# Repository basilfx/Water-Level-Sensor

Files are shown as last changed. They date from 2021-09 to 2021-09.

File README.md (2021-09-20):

# Water Level Sensor
Capacitive water level sensor based on a custom Arduino-based board.

## Introduction
This project started as an experiment to see if a water level sensor (with
fixed intervals) could be built, using the Arduino
[ADCTouch](https://github.com/martin2250/ADCTouch) library and capacitive
sensors. Capacitive sensors have the advantage that they can be isolated from
water, creating a water-tight sensor.

In this repository, you can find the CAD designs, firmware and 3D printed
parts to create a water level sensor.

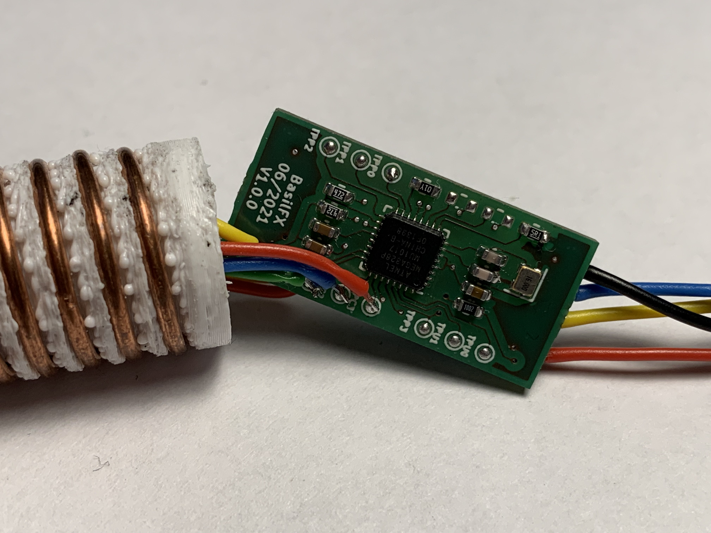
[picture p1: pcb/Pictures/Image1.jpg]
Image 1 of complete board.
[](pcb/Pictures/Image1.jpg)

## Features
* Small board that finds in a 19mm tube.
* 4 channels/board, can be daisy-chained up to 8 boards.
* I2C connection.
* Temperature sensor.

## Contents
* The `3d/` folder contains a 3D-printable designs for the necessary parts.
* The `applications/` folder contain applications and drivers that can interact
  with the sensor.
* The `firmware/` folder contains the Platform.IO-based firmware that runs on
  the sensors.
* The `pcb/` folder contains the Kicad schema and board design.

## My setup
Several proof of concepts have been built, to validate the idea and the
sensitivity of the setup in a 19mm PVC pipe (electrical conduit pipe). This
pipe was perfect for my 400 liter rain barrel, only occupying 0.5 L of water.

To create the fixed intervals, I 3D printed coils that I wound using 1.5 mm²
electrical wire. I could not get copper/aluminium tube that fitted exactly in
the 19mm tube, and this 'solution' somewhat expands against the inside of the
tube, ensuring as little as possible air between the tube and the coil.

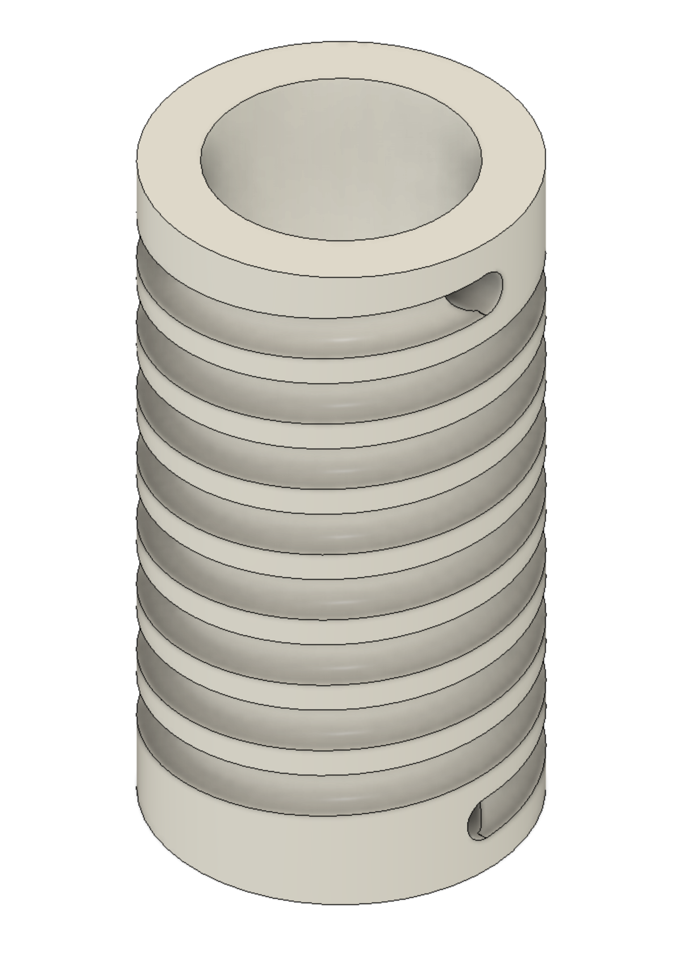
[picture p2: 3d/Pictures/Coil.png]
Actual assembly of the coil.
[](3d/Pictures/Coil.png)

In total, I used 4 sensor boards, connecting a total of 16 intervals, or
25 liter per interval. The picture below shows render of how one sensor board
is used for four intervals. Four of these assemblies are daisy-chained
together. The parent board is then connected to an external application to
read the sensor.

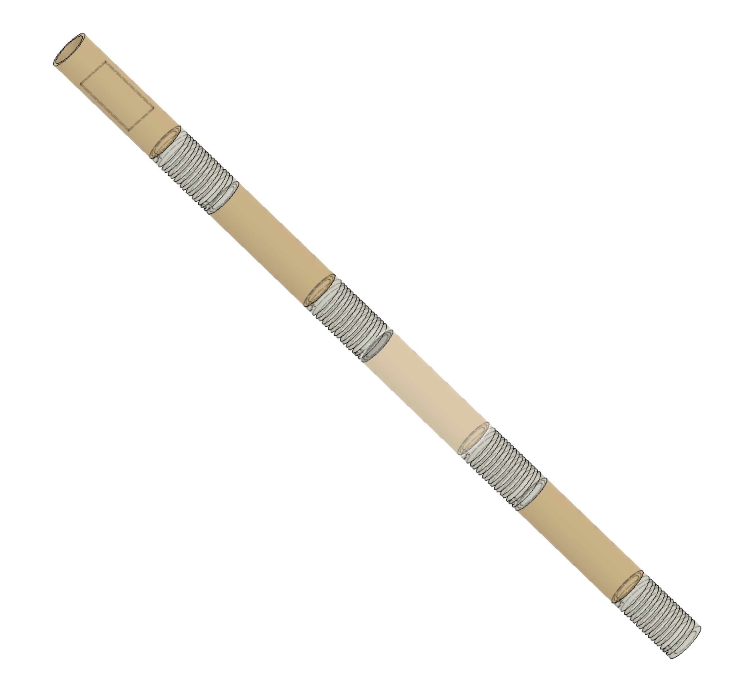
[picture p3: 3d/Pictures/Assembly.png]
3D render of assembly.
[](3d/Pictures/Assembly.png)

## License
The work in this repository is covered by CC BY-NC-SA 4.0. See the `LICENSE.md`
file for more information.

Some parts of this project are covered by a different license.

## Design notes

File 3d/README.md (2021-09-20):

# Water Level Sensor

## Pictures
[3D render of the coil.](Pictures/Coil.png)
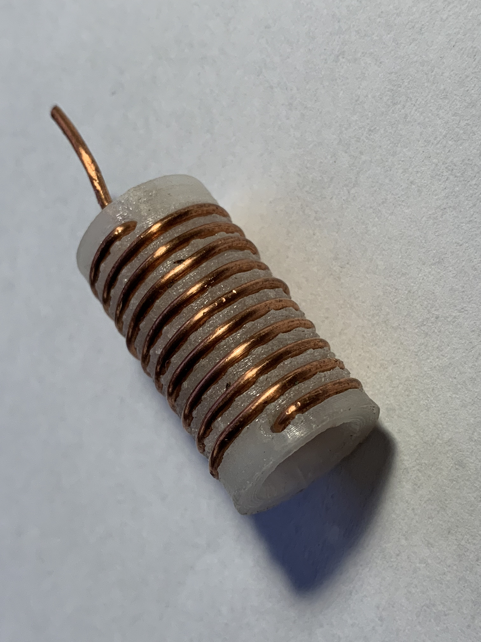
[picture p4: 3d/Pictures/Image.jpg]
Actual assembly of the coil.
[](Pictures/Image.png)

## Dimensions
The coil measures 19 mm x 30 mm.

## Print Settings
Print both parts in PETG at 0.2 mm layer height with 100% infill. Due to the
threads, it might not be as smooth as rendered, but that can be cleaned easily.

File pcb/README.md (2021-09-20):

# Water Level Sensor

## Pictures
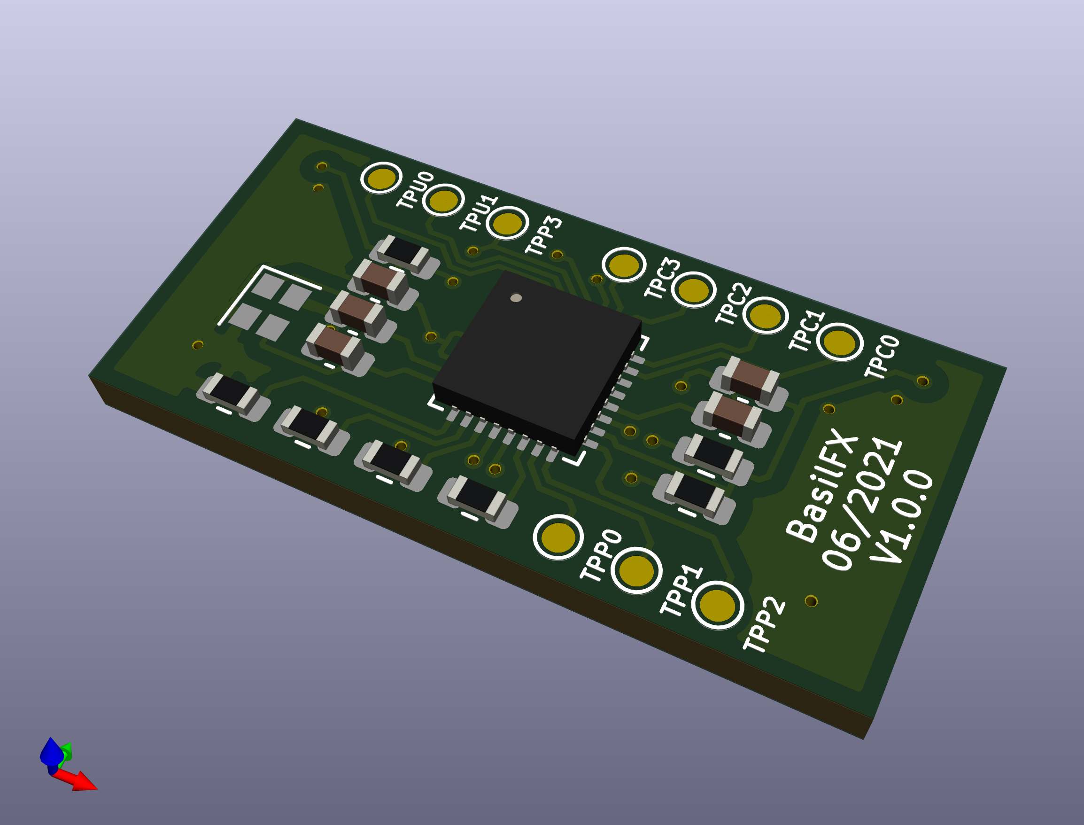
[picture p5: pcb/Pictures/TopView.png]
Top view 3D render of board.
[](Pictures/TopView.png)
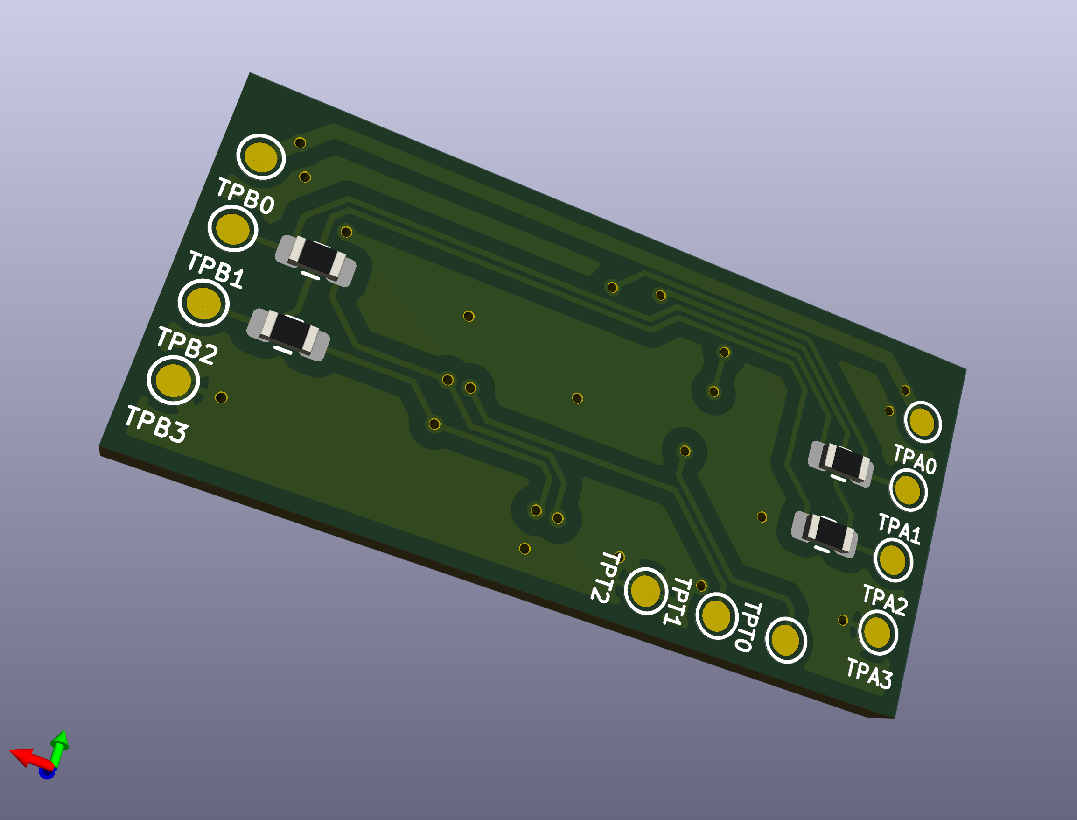
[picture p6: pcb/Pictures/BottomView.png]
Bottom view 3D render of board.
[](Pictures/BottomView.png)

[Image 1 of complete board.](Pictures/Image1.jpg)
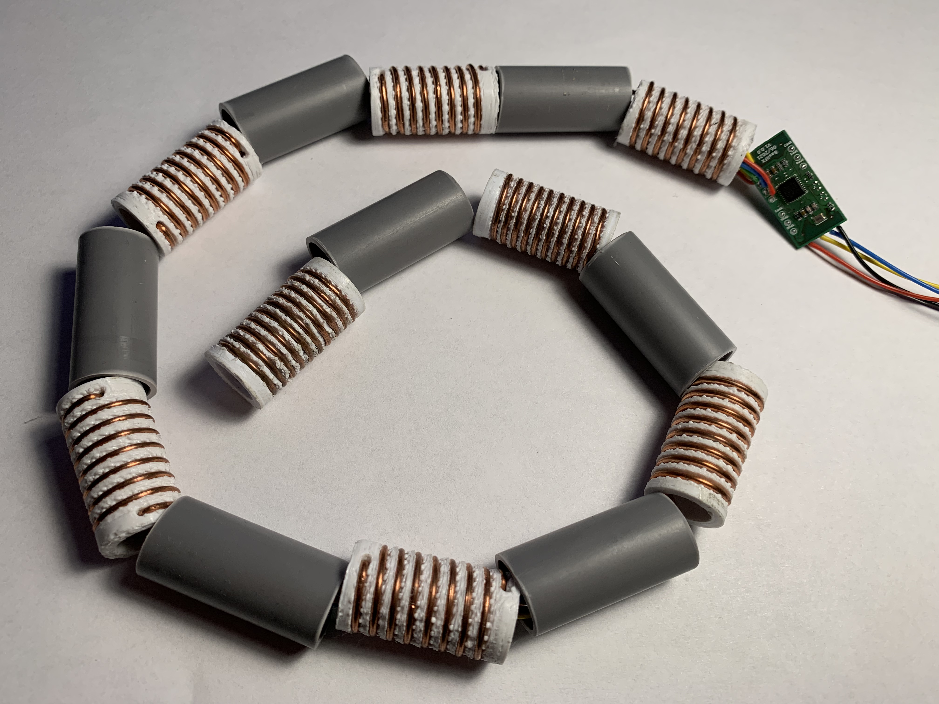
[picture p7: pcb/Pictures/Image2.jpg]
Image 2 of complete board.
[](Pictures/Image2.jpg)

## Schema
You can find the schema [here](Water-Level-Sensor.pdf).

## Mode of operation
The same board can operate in two modes:

* Parent mode
* Child mode

A chain of sensors (maximum of 7 + 1 sensors) exists out of one parent and zero
or more children. The parent will be the interface to the external application.
All children can be daisy-chained together.

```
[Application} <--> [Parent} <--> [Child 1] <--> [Child 2] <--> [Child 3]
```

Depending on the mode of operation, resistors R7-R10 must be populated
accordingly. All children are connected using a separate I2C bus.

The firmware uses R1-R3 and R11 for configuration. As of writing, the following
jumper resistors must be placed for the specific mode of operation.

| R1 | R2 | R3 | R11 | Description
|----|----|----|-----|---|
| | | | X | Parent mode, no children |
| X  | | | X | Parent mode, 1 child |
| | X  | | X | Parent mode, 2 children  |
| X  | X  | | X | Parent mode, 3 children  |
| | | | | Child mode, first child  |
| X  | | | | Child mode, second child |
| | X  | | | Child mode, third child  |
| X  | X  | | | Child mode, fourth child |

## BOM
| Ref  | Value | Footprint | Farnell | DigiKey | Notes |
|---|---|---|---|---|---|
| C1 | 1µF | Capacitor_SMD:C_0603_1608Metric | | | |
| C2 | 100nF | Capacitor_SMD:C_0603_1608Metric | | | |
| C3 | 100nF | Capacitor_SMD:C_0603_1608Metric | | | |
| C4 | 15pF | Capacitor_SMD:C_0603_1608Metric | | | |
| C5 | 15pF | Capacitor_SMD:C_0603_1608Metric | | | |
| R1 | 0 | Resistor_SMD:R_0603_1608Metric | | | |
| R2 | 0 | Resistor_SMD:R_0603_1608Metric | | | |
| R3 | 0 | Resistor_SMD:R_0603_1608Metric | | | |
| R4 | 10K | Resistor_SMD:R_0603_1608Metric | | | |
| R5 | 4K7 | Resistor_SMD:R_0603_1608Metric | | | |
| R6 | 4K7 | Resistor_SMD:R_0603_1608Metric | | | |
| R7 | 0 | Resistor_SMD:R_0603_1608Metric | | | Parent-mode only |
| R8 | 0 | Resistor_SMD:R_0603_1608Metric | | | Parent-mode only |
| R9 | 0 | Resistor_SMD:R_0603_1608Metric | | | Child-mode only  |
| R10  | 0 | Resistor_SMD:R_0603_1608Metric | | | Child-mode only  |
| R11  | 0 | Resistor_SMD:R_0603_1608Metric | | | |
| U1 | ATmega328P-MU | Package_DFN_QFN:QFN-32-1EP_5x5mm_P0.5mm_EP3.1x3.1mm | | | |
| Y1 | 16MHz | Crystal:Crystal_SMD_2016-4Pin_2.0x1.6mm | | | |

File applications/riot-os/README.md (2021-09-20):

# RIOT-OS configuration application

## Introduction
This application provides a shell to interact and configure the water level
sensor.

## Compile
To get started, download a copy of [RIOT-OS](https://github.com/RIOT-OS/RIOT)
in this folder. Version 2021.07 is known to work.

Then, navigate to the `firmware/` folder. Adapt the `Makefile` and run
`make flash` to compile and flash.

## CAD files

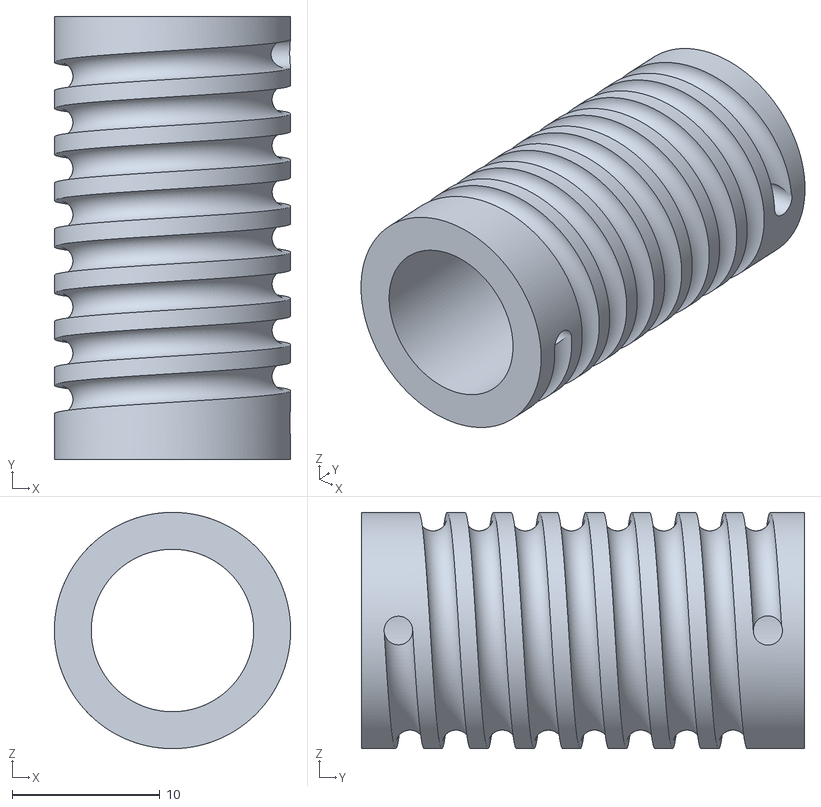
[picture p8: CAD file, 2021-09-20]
3d/Coil.stl
16.0 x 30.0 x 16.0

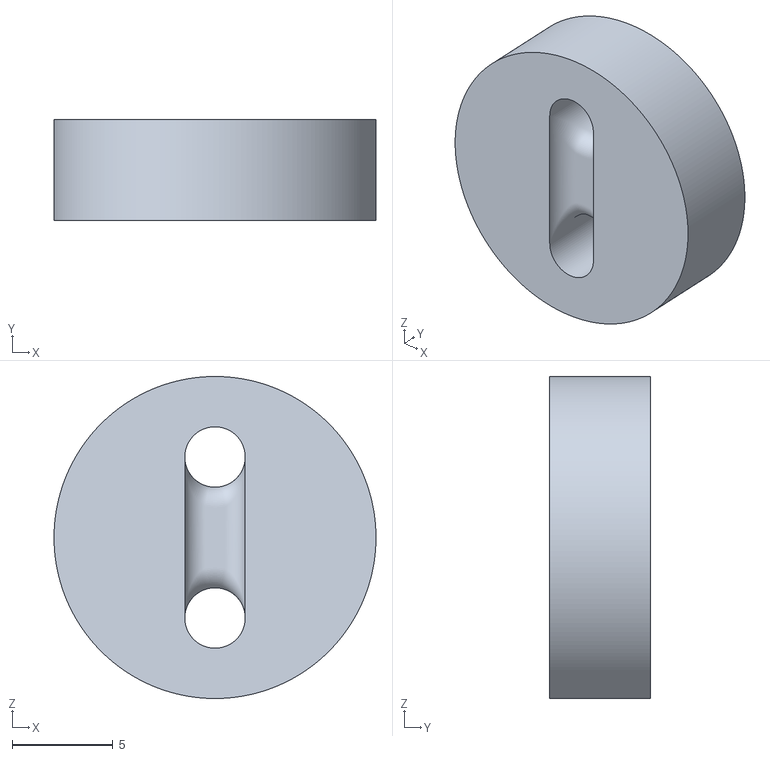
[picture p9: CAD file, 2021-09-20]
3d/End-Cap.stl
16.0 x 5.00 x 16.0

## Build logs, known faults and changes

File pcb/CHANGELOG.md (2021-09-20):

# Changelog

## v1.0.0
Released 20 September 2021

Highlights:
* Initial version.

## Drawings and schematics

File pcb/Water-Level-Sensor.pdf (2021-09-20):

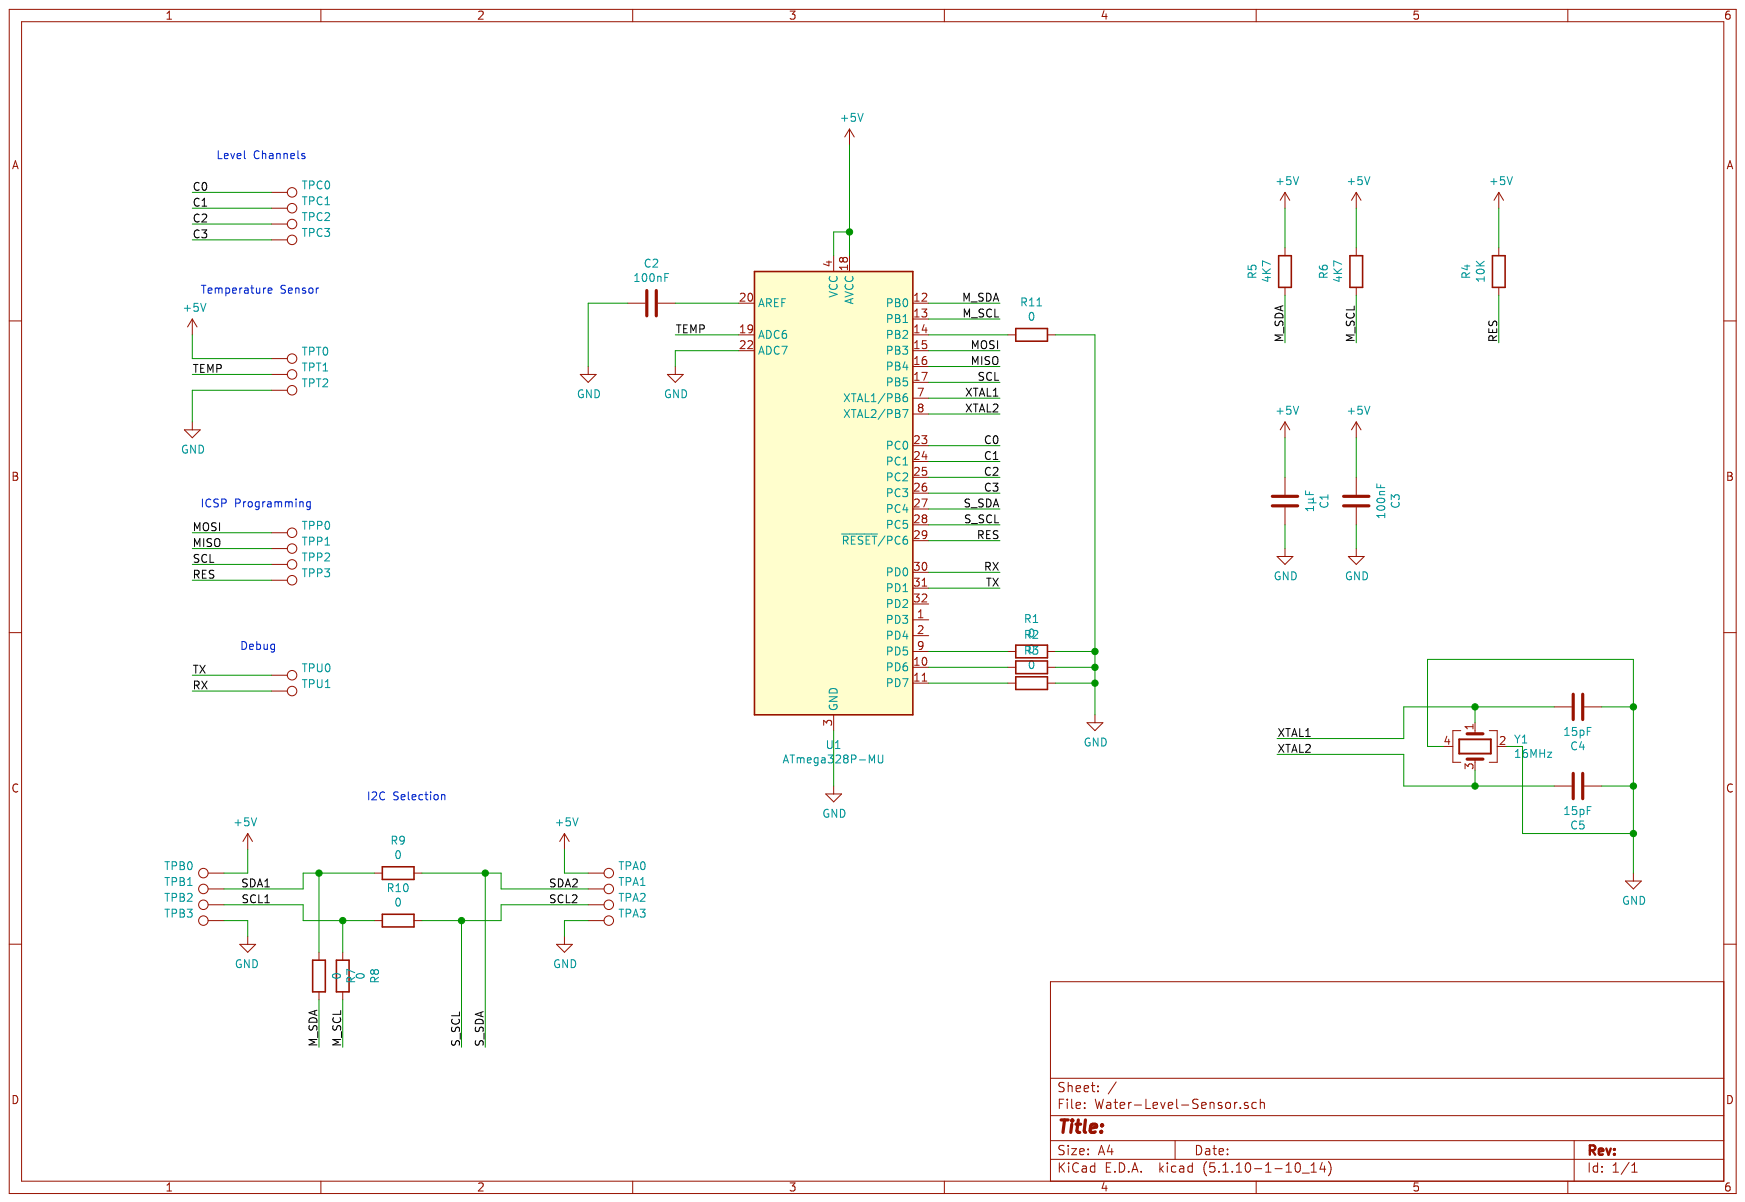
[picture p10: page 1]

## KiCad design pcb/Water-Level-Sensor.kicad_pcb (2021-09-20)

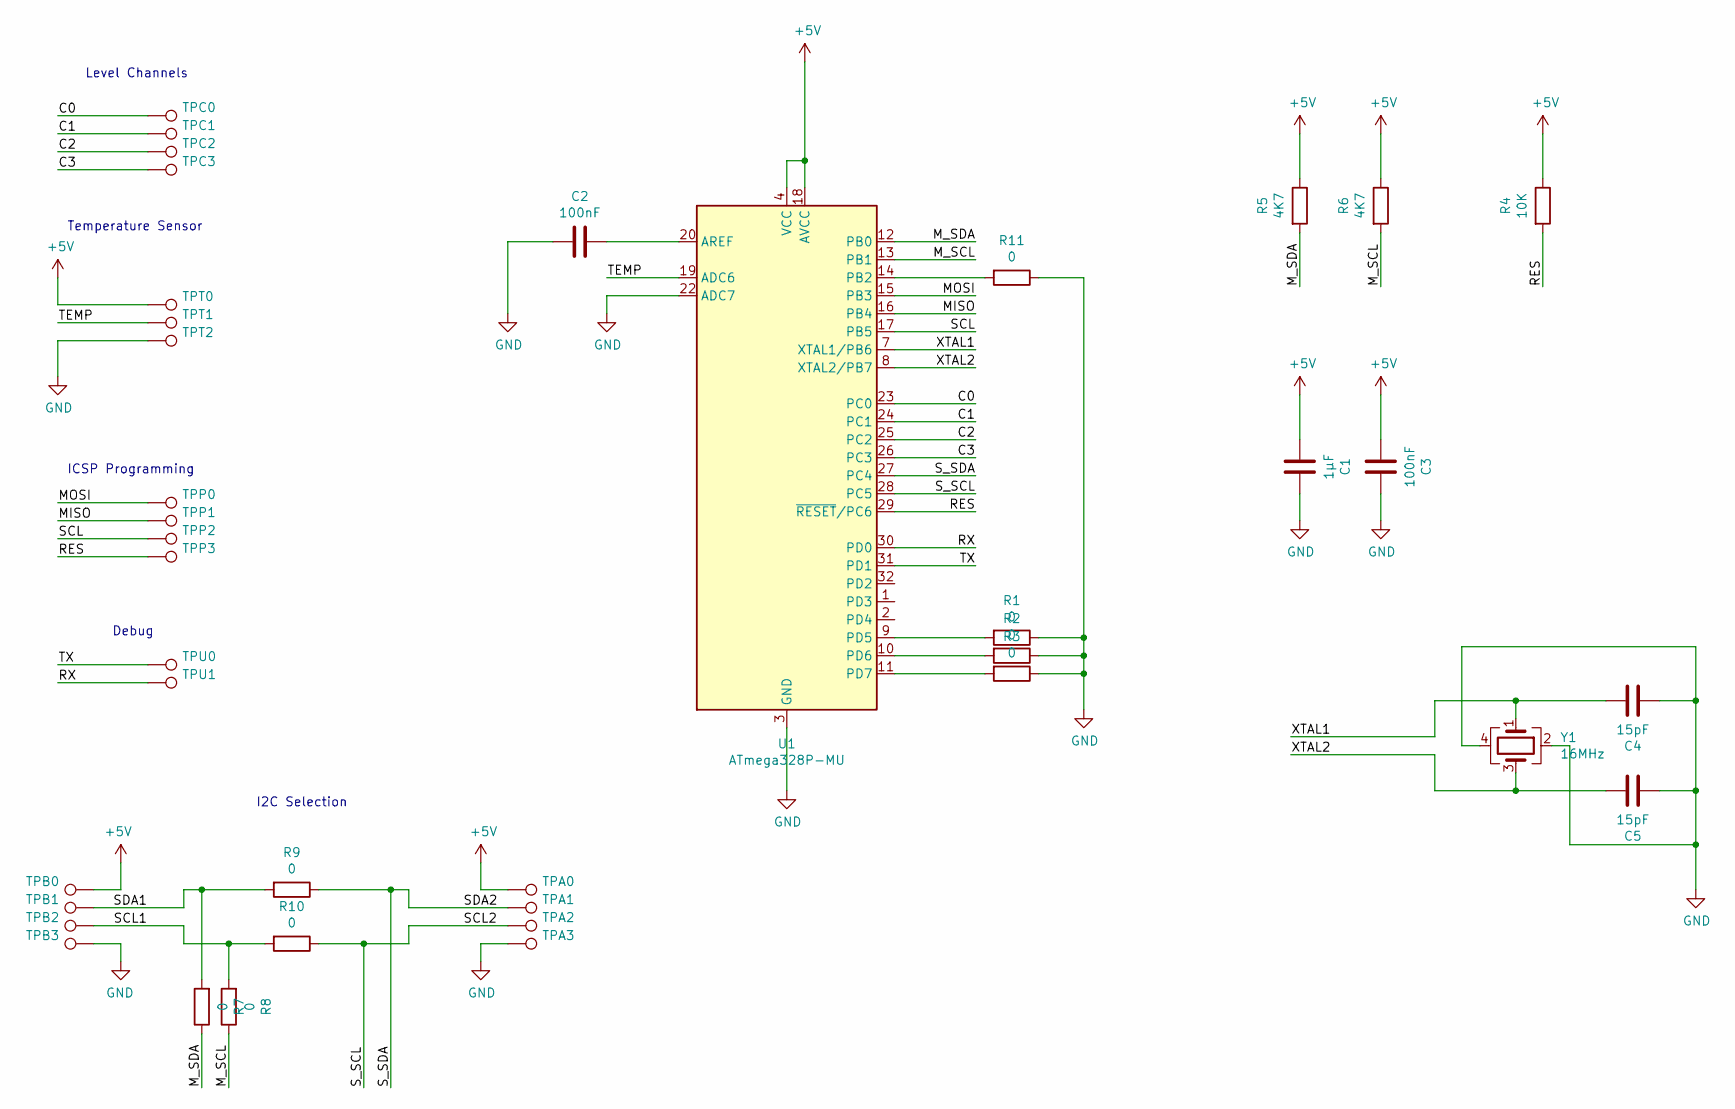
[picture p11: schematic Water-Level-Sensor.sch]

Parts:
C1: 1µF; C_0603_1608Metric
C2, C3: 100nF; C_0603_1608Metric
C4, C5: 15pF; C_0603_1608Metric
R1, R2, R3, R7, R8, R9, R10, R11: 0; R_0603_1608Metric
R4: 10K; R_0603_1608Metric
R5, R6: 4K7; R_0603_1608Metric
TPA0: 5V; TestPoint_Pad_D1.0mm
TPA1: SDA; TestPoint_Pad_D1.0mm
TPA2: SCL; TestPoint_Pad_D1.0mm
TPA3: GND; TestPoint_Pad_D1.0mm
TPB0: 5V; TestPoint_Pad_D1.0mm
TPB1: SDA; TestPoint_Pad_D1.0mm
TPB2: SCL; TestPoint_Pad_D1.0mm
TPB3: GND; TestPoint_Pad_D1.0mm
TPC0: C0; TestPoint_Pad_D1.0mm
TPC1: C1; TestPoint_Pad_D1.0mm
TPC2: C2; TestPoint_Pad_D1.0mm
TPC3: C3; TestPoint_Pad_D1.0mm
TPP0, TPP1, TPP2, TPP3: TestPoint; TestPoint_Pad_D1.0mm
TPT0, TPT1, TPT2: TestPoint; TestPoint_Pad_D1.0mm
TPU0: TX; TestPoint_Pad_D1.0mm
TPU1: RX; TestPoint_Pad_D1.0mm
U1: ATmega328P-MU; QFN-32-1EP_5x5mm_P0.5mm_EP3.1x3.1mm
Y1: 16MHz; Crystal_SMD_2016-4Pin_2.0x1.6mm

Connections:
+5V: C1.2, C3.2, R4.1, R5.1, R6.1, TPA0.1, TPB0.1, TPT0.1, U1.4 (VCC), U1.6 (VCC), U1.18 (AVCC)
/C0: TPC0.1, U1.23 (PC0)
/C1: TPC1.1, U1.24 (PC1)
/C2: TPC2.1, U1.25 (PC2)
/C3: TPC3.1, U1.26 (PC3)
/MISO: TPP1.1, U1.16 (PB4)
/MOSI: TPP0.1, U1.15 (PB3)
/M_SCL: R6.2, R8.1, U1.13 (PB1)
/M_SDA: R5.2, R7.1, U1.12 (PB0)
/RES: R4.2, TPP3.1, U1.29 (~RESET~/PC6)
/RX: TPU1.1, U1.30 (PD0)
/SCL: TPP2.1, U1.17 (PB5)
/SCL1: R8.2, R10.2, TPB2.1
/SCL2: R10.1, TPA2.1, U1.28 (PC5)
/SDA1: R7.2, R9.2, TPB1.1
/SDA2: R9.1, TPA1.1, U1.27 (PC4)
/TEMP: TPT1.1, U1.19 (ADC6)
/TX: TPU0.1, U1.31 (PD1)
/XTAL1: C4.1, U1.7 (XTAL1/PB6), Y1.1
/XTAL2: C5.1, U1.8 (XTAL2/PB7), Y1.3
GND: C1.1, C2.2, C3.1, C4.2, C5.2, R1.1, R2.1, R3.1, R11.1, TPA3.1, TPB3.1, TPT2.1, U1.3 (GND), U1.5 (GND), U1.21 (GND), U1.22 (ADC7), U1.33 (GND), Y1.2, Y1.4
unnamed: C2.1, U1.20 (AREF)
unnamed: R1.2, U1.9 (PD5)
unnamed: R2.2, U1.10 (PD6)
unnamed: R3.2, U1.11 (PD7)
unnamed: R11.2, U1.14 (PB2)

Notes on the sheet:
Level Channels
Temperature Sensor
ICSP Programming
Debug
I2C Selection

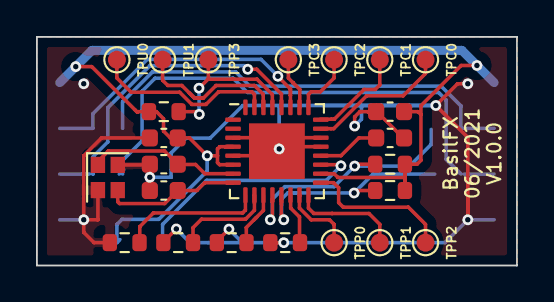
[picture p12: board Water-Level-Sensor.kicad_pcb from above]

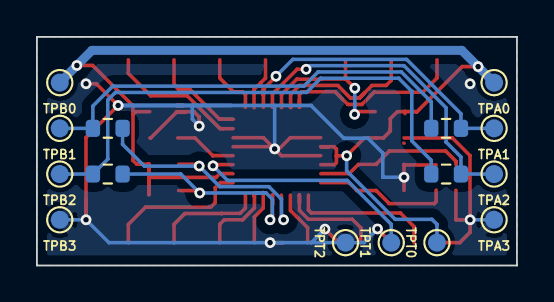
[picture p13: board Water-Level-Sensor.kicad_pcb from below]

Board: 2 copper layers, 26.7 x 12.7 mm, 39 parts (15 on the bottom side), 26 nets.

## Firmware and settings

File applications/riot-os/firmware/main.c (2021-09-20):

/*
 * Copyright (C) 2021 Bas Stottelaar <basstottelaar@gmail.com>
 *
 * This file is subject to the terms and conditions of the GNU Lesser
 * General Public License v2.1. See the file LICENSE in the top level
 * directory for more details.
 */

#include <stdio.h>
#include <stdlib.h>
#include <string.h>

#include "water_sensor.h"
#include "water_sensor_internals.h"

#include "board.h"
#include "xtimer.h"
#include "shell.h"

#if IS_ACTIVE(MODULE_U8G2)
#include "u8g2.h"
#include "u8x8_riotos.h"

#include "images.h"
#endif

/* forward declarations */
int reset(int argc, char **argv);
int enable(int argc, char **argv);
int load(int argc, char **argv);
int store(int argc, char **argv);
int calibrate(int argc, char **argv);
int zero(int argc, char **argv);
int info(int argc, char **argv);
int level(int argc, char **argv);
int temperature(int argc, char **argv);
int level_raw(int argc, char **argv);
int temperature_raw(int argc, char **argv);
int config(int argc, char **argv);
int level_config(int argc, char **argv);
int temperature_config(int argc, char **argv);

#if IS_ACTIVE(MODULE_U8G2)
int monitor(int argc, char **argv);

static u8g2_t u8g2;
#endif

static water_sensor_params_t params = {
    .i2c_dev = I2C_DEV(0),
    .address = WATER_SENSOR_I2C_ADDRESS
};

static water_sensor_t dev;
static water_sensor_info_t dev_info;

static const shell_command_t shell_commands[] = {
    { "reset", "Reset water sensor", reset },
    { "enable", "Enable water sensor", enable },
    { "load", "Load configuration command", load },
    { "store", "Store configuration command", store },
    { "calibrate", "Calibrate water sensor", calibrate },
    { "zero", "Zero min/max", zero },
    { "info", "Read water sensor info", info },
    { "level", "Read the level", level },
    { "temperature", "Read the temperature", temperature },
    { "level_raw", "Read the level raw", level_raw },
    { "temperature_raw", "Read the temperature raw", temperature_raw },
    { "config", "Read or write global config", config },
    { "level_config", "Read or write level config", level_config },
    { "temperature_config", "Read or write temperature config", temperature_config },
#if IS_ACTIVE(MODULE_U8G2)
    { "monitor", "Enable monitor mode on LCD", monitor },
#endif
    { NULL, NULL, NULL }
};

int reset(int argc, char **argv)
{
    (void)argc;
    (void)argv;

    int result = water_sensor_reset(&dev);

    if (result != WATER_SENSOR_OK) {
        printf("error: return code %d\n", result);
        return 1;
    }

    return 0;
}

int enable(int argc, char **argv)
{
    (void)argc;
    (void)argv;

    int result = water_sensor_enable(&dev);

    if (result != WATER_SENSOR_OK) {
        printf("error: return code %d\n", result);
        return 1;
    }

    return 0;
}

int load(int argc, char **argv)
{
    (void)argc;
    (void)argv;

    int result = water_sensor_load(&dev);

    if (result != WATER_SENSOR_OK) {
        printf("error: return code %d\n", result);
        return 1;
    }

    return 0;
}

int store(int argc, char **argv)
{
    (void)argc;
    (void)argv;

    int result = water_sensor_store(&dev);

    if (result != WATER_SENSOR_OK) {
        printf("error: return code %d\n", result);
        return 1;
    }

    return 0;
}

int calibrate(int argc, char **argv)
{
    (void)argc;
    (void)argv;

    int result = water_sensor_calibrate(&dev);

    if (result != WATER_SENSOR_OK) {
        printf("error: return code %d\n", result);
        return 1;
    }

    return 0;
}

int zero(int argc, char **argv)
{
    (void)argc;
    (void)argv;

    int result = water_sensor_zero(&dev);

    if (result != WATER_SENSOR_OK) {
        printf("error: return code %d\n", result);
        return 1;
    }

    return 0;
}

int info(int argc, char **argv)
{
    (void)argc;
    (void)argv;

    water_sensor_info_t info;

    int result = water_sensor_read_info(&dev, &info);

    if (result != WATER_SENSOR_OK) {
        printf("error: return code %d\n", result);
        return 1;
    }

    printf("Identifier: %02x\n", info.id);
    printf("Level channels: %d\n", info.level_channels);
    printf("Temperature channels: %d\n", info.temperature_channels);
    printf("Enabled: %s\n", info.enabled ? "Y" : "N");

    printf("Errors: ");

    if (info.errors) {
        char *delimeter = "";

        if (info.errors & (1 << WATER_SENSOR_INFO_ERRORS_INIT)) {
            printf("%sinit", delimeter);
            delimeter = ", ";
        }
        if (info.errors & (1 << WATER_SENSOR_INFO_ERRORS_RESET)) {
            printf("%sreset", delimeter);
            delimeter = ", ";
        }
        if (info.errors & (1 << WATER_SENSOR_INFO_ERRORS_ENABLE)) {
            printf("%senable", delimeter);
            delimeter = ", ";
        }
        if (info.errors & (1 << WATER_SENSOR_INFO_ERRORS_READ)) {
            printf("%sread", delimeter);
            delimeter = ", ";
        }
        if (info.errors & (1 << WATER_SENSOR_INFO_ERRORS_ZERO)) {
            printf("%szero", delimeter);
            delimeter = ", ";
        }

        printf("\n");
    }
    else {
        printf("none\n");
    }

    printf("Context: %s\n", info.context ? "Y" : "N");

    return 0;
}

int level(int argc, char **argv)
{
    (void)argc;
    (void)argv;

    water_sensor_level_t level;

    int result = water_sensor_read_level(&dev, &level);

    if (result != WATER_SENSOR_OK) {
        printf("error: return code %d\n", result);
        return 1;
    }

    printf("Level: %d\n", level.value);
    printf("Channel: %d\n", level.channel);
    printf("Valid: %s\n", level.valid ? "Y" : "N");

    return 0;
}

int temperature(int argc, char **argv)
{
    (void)argc;
    (void)argv;

    water_sensor_temperature_t temperature;

    int result = water_sensor_read_temperature(&dev, &temperature);

    if (result != WATER_SENSOR_OK) {
        printf("error: return code %d\n", result);
        return 1;
    }

    printf("Temperature: %d\n", temperature.value);
    printf("Channel: %d\n", temperature.channel);
    printf("Valid: %s\n", temperature.valid ? "Y" : "N");

    return 0;
}

int level_raw(int argc, char **argv)
{
    unsigned start, stop;

    if (argc == 1) {
        start = 0;
        stop = dev_info.level_channels;
    } else if (argc == 2) {
        int channel = atoi(argv[1]);

        start = channel;
        stop = channel + 1;
    } else {
        printf("usage: %s [<channel>]\n", argv[0]);
        return 0;
    }

    water_sensor_level_raw_t level_raw;
    water_sensor_level_config_t level_config;

    printf("Channel\tValue\tMin\tMax\tDelta\tValid\tState\n");

    for (unsigned i = start; i < stop; i++) {
        int result = water_sensor_read_level_raw(&dev, i, &level_raw);

        if (result != WATER_SENSOR_OK) {
            printf("error: return code %d\n", result);
            return 1;
        }

        result = water_sensor_read_level_config(&dev, i, &level_config);

        if (result != WATER_SENSOR_OK) {
            printf("error: return code %d\n", result);
            return 1;
        }

        if (level_config.enabled) {
            printf("%02d\t%d\t%d\t%d\t%d\t%s\t%s\n", i, level_raw.value, level_raw.min, level_raw.max, level_raw.max - level_raw.min, level_raw.valid ? "Y" : "N", level_raw.value > level_config.offset ? "Y" : "N");
        }
        else {
            printf("%02d\t--\t--\t--\n", i);
        }
    }

    return 0;
}

int temperature_raw(int argc, char **argv)
{
    unsigned start, stop;

    if (argc == 1) {
        start = 0;
        stop = dev_info.temperature_channels;
    } else if (argc == 2) {
        int channel = atoi(argv[1]);

        start = channel;
        stop = channel + 1;
    } else {
        printf("usage: %s [<channel>]\n", argv[0]);
        return 0;
    }

    water_sensor_temperature_raw_t temperature_raw;
    water_sensor_temperature_config_t temperature_config;

    printf("Channel\tValue\tMin\tMax\tDelta\tValid\n");

    for (unsigned i = start; i < stop; i++) {
        int result = water_sensor_read_temperature_raw(&dev, i, &temperature_raw);

        if (result != WATER_SENSOR_OK) {
            printf("error: return code %d\n", result);
            return 1;
        }

        result = water_sensor_read_temperature_config(&dev, i, &temperature_config);

        if (result != WATER_SENSOR_OK) {
            printf("error: return code %d\n", result);
            return 1;
        }

        if (temperature_config.enabled) {
            printf("%02d\t%d\t%d\t%d\t%d\t%s\n", i, temperature_raw.value, temperature_raw.min, temperature_raw.max, temperature_raw.max - temperature_raw.min, temperature_raw.valid ? "Y" : "N");
        }
        else {
            printf("%02d\t--\t--\t--\t--\t--\n", i);
        }
    }

    return 0;
}

int config_get(int argc, char **argv)
{
    (void) argc;
    (void) argv;

    water_sensor_config_t config;

    int result = water_sensor_read_config(&dev, &config);

    if (result != WATER_SENSOR_OK) {
        printf("error: return code %d\n", result);
        return 1;
    }

    printf("Default level: %d\n", config.default_level);

    return 0;
}

int config_set(int argc, char **argv)
{
    if (argc < 3) {
        printf("usage: %s %s <default level>\n", argv[0], argv[1]);
        return 0;
    }

    water_sensor_config_t config;

    config.default_level = atoi(argv[2]);

    int result = water_sensor_write_config(&dev, &config);

    if (result != WATER_SENSOR_OK) {
        printf("error: return code %d\n", result);
        return 1;
    }

    return 0;
}

int config(int argc, char **argv)
{
    if (argc < 2) {
        printf("usage: %s <get|set>\n", argv[0]);
        return 0;
    }

    if (strcmp(argv[1], "get") == 0) {
        return config_get(argc, argv);
    } else if (strcmp(argv[1], "set") == 0) {
        return config_set(argc, argv);
    } else {
        printf("error: '%s' not supported\n", argv[1]);
        return 1;
    }

    return 0;
}

int level_config_get(int argc, char **argv)
{
    unsigned start, stop;

    if (argc == 2) {
        start = 0;
        stop = dev_info.level_channels;
    } else if (argc == 3) {
        int channel = atoi(argv[2]);

        start = channel;
        stop = channel + 1;
    } else {
        printf("usage: %s %s [<channel>]\n", argv[0], argv[1]);
        return 0;
    }

    water_sensor_level_config_t config;

    printf("Channel\tEnabled\tSamples\tAlpha\tOffset\tLevel\n");

    for (unsigned i = start; i < stop; i++) {
        int result = water_sensor_read_level_config(&dev, i, &config);

        if (result != WATER_SENSOR_OK) {
            printf("error: return code %d\n", result);
            return 1;
        }

        printf("%02d\t%s\t%d\t%d\t%d\t%d\n", i, config.enabled ? "Y" : "N", config.samples, config.alpha, config.offset, config.level);
    }

    return 0;
}

int level_config_set(int argc, char **argv)
{
    if (argc < 8) {
        printf("usage: %s %s <channel> <enabled> <samples> <alpha> <offset> <level>\n", argv[0], argv[1]);
        return 0;
    }

    int channel = atoi(argv[2]);

    water_sensor_level_config_t config;

    config.enabled = atoi(argv[3]);
    config.samples = atoi(argv[4]);
    config.alpha = atoi(argv[5]);
    config.offset = atoi(argv[6]);
    config.level = atoi(argv[7]);

    int result = water_sensor_write_level_config(&dev, channel, &config);

    if (result != WATER_SENSOR_OK) {
        printf("error: return code %d\n", result);
        return 1;
    }

    return 0;
}

int level_config(int argc, char **argv)
{
    if (argc < 2) {
        printf("usage: %s <get|set>\n", argv[0]);
        return 0;
    }

    if (strcmp(argv[1], "get") == 0) {
        return level_config_get(argc, argv);
    } else if (strcmp(argv[1], "set") == 0) {
        return level_config_set(argc, argv);
    } else {
        printf("error: '%s' not supported\n", argv[1]);
        return 1;
    }

    return 0;
}

int temperature_config_get(int argc, char **argv)
{
    unsigned start, stop;

    if (argc == 2) {
        start = 0;
        stop = dev_info.temperature_channels;
    } else if (argc == 3) {
        int channel = atoi(argv[2]);

        start = channel;
        stop = channel + 1;
    } else {
        printf("usage: %s %s [<channel>]\n", argv[0], argv[1]);
        return 0;
    }

    water_sensor_temperature_config_t config;

    printf("Channel\tEnabled\tAlpha\tReference\n");

    for (unsigned i = start; i < stop; i++) {
        int result = water_sensor_read_temperature_config(&dev, i, &config);

        if (result != WATER_SENSOR_OK) {
            printf("error: return code %d\n", result);
            return 1;
        }

        printf("%02d\t%s\t%d\t%d\n", i, config.enabled ? "Y" : "N", config.alpha, config.reference);
    }

    return 0;
}

int temperature_config_set(int argc, char **argv)
{
    if (argc < 6) {
        printf("usage: %s %s <channel> <enabled> <alpha> <reference>\n", argv[0], argv[1]);
        return 0;
    }

    int channel = atoi(argv[2]);

    water_sensor_temperature_config_t config;

    config.enabled = atoi(argv[3]);
    config.alpha = atoi(argv[4]);
    config.reference = atoi(argv[5]);

    int result = water_sensor_write_temperature_config(&dev, channel, &config);

    if (result != WATER_SENSOR_OK) {
        printf("error: return code %d\n", result);
        return 1;
    }

    return 0;
}

int temperature_config(int argc, char **argv)
{
    if (argc < 2) {
        printf("usage: %s <get|set>\n", argv[0]);
        return 0;
    }

    if (strcmp(argv[1], "get") == 0) {
        return temperature_config_get(argc, argv);
    } else if (strcmp(argv[1], "set") == 0) {
        return temperature_config_set(argc, argv);
    } else {
        printf("error: '%s' not supported\n", argv[1]);
        return 1;
    }

    return 0;
}

int monitor(int argc, char **argv)
{
    (void) argc;
    (void) argv;

    char buffer[3][32];

    water_sensor_level_t level;
    water_sensor_level_raw_t level_raw;
    water_sensor_temperature_t temperature;

    puts("Reset board to restart shell.");

    gpio_init(DISP_COM_PIN, GPIO_OUT);
    gpio_init(DISP_EN_PIN, GPIO_OUT);

    gpio_set(DISP_COM_PIN);
    gpio_set(DISP_EN_PIN);

    u8g2_Setup_ls013b7dh03_128x128_1(&u8g2, U8G2_R0, u8x8_byte_hw_spi_riotos, u8x8_gpio_and_delay_riotos);

    u8x8_riotos_t user_data =
    {
        .device_index = DISP_SPI,
        .pin_cs = DISP_CS_PIN,
    };

    u8g2_SetUserPtr(&u8g2, &user_data);

    u8g2_InitDisplay(&u8g2);
    u8g2_SetPowerSave(&u8g2, 0);

    while (1) {
        int result = water_sensor_read_level(&dev, &level);

        if (result != WATER_SENSOR_OK) {
            printf("error: return code %d\n", result);
        }

        result = water_sensor_read_temperature(&dev, &temperature);

        if (result != WATER_SENSOR_OK) {
            printf("error: return code %d\n", result);
        }

        snprintf(buffer[0], 32, "%i (%d, %s)", level.value, level.channel, level.valid ? "Y" : "N");
        snprintf(buffer[1], 32, "%i.%02i C (%d, %s)", temperature.value / 100, temperature.value % 100, temperature.channel, temperature.valid ? "Y" : "N");

        u8g2_FirstPage(&u8g2);

        do {
            u8g2_SetDrawColor(&u8g2, 1);
            u8g2_SetFont(&u8g2, u8g2_font_helvB12_tf);

            /* humidity */
            u8g2_DrawBitmap(&u8g2, 2, 20 - 16 + 2, 2, 16, image_rh);
            u8g2_DrawStr(&u8g2, 25, 20, buffer[0]);

            /* temperature */
            u8g2_DrawBitmap(&u8g2, 2, 40 - 16 + 2, 2, 16, image_temperature);
            u8g2_DrawStr(&u8g2, 25, 40, buffer[1]);

            u8g2_SetFont(&u8g2, u8g2_font_helvB08_tf);

            for (int i = 0; i < dev_info.level_channels; i++) {
                result = water_sensor_read_level_raw(&dev, i, &level_raw);

                if (result != WATER_SENSOR_OK) {
                    printf("error: return code %d\n", result);
                }

                snprintf(buffer[2], 32, "%d: %d (%s) %s %d/%d/%d", i, level_raw.value, level.valid ? "Y" : "N", i == level.channel ? "<--" : "   ",
                    level_raw.min, level_raw.max, level_raw.max - level_raw.min);

                u8g2_DrawStr(&u8g2, 2, 55 + (i * 9), buffer[2]);
            }

        } while (u8g2_NextPage(&u8g2));

        /* go to sleep */
        xtimer_msleep(250);
    }

    return 0;
}

int main(void)
{
    puts("Initializing sensor.");

    if (water_sensor_init(&dev, &params) != WATER_SENSOR_OK) {
        puts("Failed");
        return 1;
    }

    if (water_sensor_read_info(&dev, &dev_info) != WATER_SENSOR_OK) {
        puts("Failed");
        return 1;
    }

    printf("Detected water sensor with %d level channels and %d temperature channels.\n", dev_info.level_channels, dev_info.temperature_channels);

    /* start shell */
    char line_buf[SHELL_DEFAULT_BUFSIZE];
    shell_run(shell_commands, line_buf, SHELL_DEFAULT_BUFSIZE);

    /* should be never reached */
    return 0;
}

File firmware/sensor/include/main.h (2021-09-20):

#pragma once

#include <stdint.h>

#define NUM_SENSORS 8U
#define NUM_CHANNELS 4U

#define PIN_CONFIG_0 5
#define PIN_CONFIG_1 6
#define PIN_CONFIG_2 7
#define PIN_CONFIG_3 10

#define PIN_MASTER_SDA 8
#define PIN_MASTER_SCL 9

#define PIN_TEMPERATURE 6

#define CONFIG_MAGIC 0xbaab1234

typedef struct {
    uint8_t id;
    uint8_t index;
    uint8_t children;
} info_t;

typedef struct {
    struct {
        bool enabled;
        uint8_t samples;
        uint8_t alpha;
        uint16_t offset;
        int16_t level;
    } adc[NUM_CHANNELS];

    struct {
        uint8_t alpha;
        uint16_t reference;
        bool enabled;
    } temperature;
} config_sensor_t;

typedef struct {
    uint32_t magic;

    int16_t defaultLevel;

    config_sensor_t sensors[NUM_SENSORS];
} config_t;

typedef struct {
    struct {
        uint16_t value;
        uint16_t min;
        uint16_t max;
        bool valid;
    } adc[NUM_CHANNELS];

    struct {
        int16_t value;
        int16_t min;
        int16_t max;
        bool valid;
    } temperature;
} state_sensor_t;

typedef struct {
    bool enabled;

    uint8_t errors;
    uint8_t context;

    struct {
        int16_t value;
        int8_t channel;
        bool valid;
    } level;

    struct {
        int16_t value;
        int8_t channel;
        bool valid;
    } temperature;

    state_sensor_t sensors[NUM_SENSORS];
} state_t;

void reset();
void init();
void enable();
void store();
void load();
void calibrate();
void zero();

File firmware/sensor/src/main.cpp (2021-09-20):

#include <stdint.h>

#include <ADCTouch.h>
#include <Arduino.h>
#include <EEPROM.h>
#include <HardWire.h>
#include <SoftWire.h>

#include "main.h"
#include "water_sensor.h"

static info_t info;
static config_t config;
static state_t state;

static WaterSensor waterSensor[NUM_SENSORS];

static SoftWire Wire2(PIN_MASTER_SDA, PIN_MASTER_SCL);

static char swTxBuffer[32];
static char swRxBuffer[32];

static AsyncDelay readTimer;
static AsyncDelay updateTimer;

// I2C response structure.
static struct {
    uint8_t buffer[32];
    size_t length;
    bool nack;
} response;

static bool _read(size_t length)
{
    uint8_t checksum = 0xff;

    for (unsigned i = 0; i < length; i++) {
        response.buffer[i] = Wire.read();
        checksum ^= response.buffer[i];
    }

    return checksum == Wire.read();
}

void receiveEvent(int countToRead)
{
    // Reset response, so that no stale date is read.
    response.length = 0;
    response.nack = false;

    // Read the command.
    uint8_t data = Wire.read();

    // Serial.print("Parent data: ");
    // Serial.println(data, HEX);

    switch (data) {
        case WATER_SENSOR_RESET:
        {
            reset();
            break;
        }
        case WATER_SENSOR_ENABLE:
        {
            enable();
            break;
        }
        case WATER_SENSOR_LOAD:
        {
            load();
            break;
        }
        case WATER_SENSOR_STORE:
        {
            store();
            break;
        }
        case WATER_SENSOR_CALIBRATE:
        {
            calibrate();
            break;
        }
        case WATER_SENSOR_ZERO:
        {
            zero();
            break;
        }
        case WATER_SENSOR_READ_INFO:
        {
            int sensors = 1 + info.children;

            response.buffer[0] = info.id;
            response.buffer[1] = sensors * NUM_CHANNELS;
            response.buffer[2] = sensors;
            response.buffer[3] = state.enabled ? 1 : 0;
            response.buffer[4] = state.errors;
            response.buffer[5] = state.context;

            response.length = WATER_SENSOR_INFO_SIZE;

            break;
        }
        case WATER_SENSOR_READ_LEVEL:
        {
            response.buffer[0] = (state.level.value & 0xff00) >> 8;
            response.buffer[1] = (state.level.value & 0x00ff) >> 0;
            response.buffer[2] = state.level.channel;
            response.buffer[3] = state.level.valid;

            response.length = WATER_SENSOR_LEVEL_SIZE;

            break;
        }
        case WATER_SENSOR_READ_TEMPERATURE:
        {
            response.buffer[0] = (state.temperature.value & 0xff00) >> 8;
            response.buffer[1] = (state.temperature.value & 0x00ff) >> 0;
            response.buffer[2] = state.temperature.channel;
            response.buffer[3] = state.temperature.valid;

            response.length = WATER_SENSOR_TEMPERATURE_SIZE;

            break;
        }
        case WATER_SENSOR_READ_LEVEL_RAW:
        {
            if (countToRead != 2) {
                response.nack = true;
                return;
            }

            int channel = Wire.read();

            int i = channel / NUM_CHANNELS;
            int j = channel % NUM_CHANNELS;

            response.buffer[0] = (state.sensors[i].adc[j].value & 0xff00) >> 8;
            response.buffer[1] = (state.sensors[i].adc[j].value & 0x00ff) >> 0;
            response.buffer[2] = (state.sensors[i].adc[j].min & 0xff00) >> 8;
            response.buffer[3] = (state.sensors[i].adc[j].min & 0x00ff) >> 0;
            response.buffer[4] = (state.sensors[i].adc[j].max & 0xff00) >> 8;
            response.buffer[5] = (state.sensors[i].adc[j].max & 0x00ff) >> 0;
            response.buffer[6] = state.sensors[i].adc[j].valid;

            response.length = WATER_SENSOR_LEVEL_RAW_SIZE;

            break;
        }
        case WATER_SENSOR_READ_TEMPERATURE_RAW:
        {
            if (countToRead != 2) {
                response.nack = true;
                return;
            }

            int channel = Wire.read();

            int i = channel % NUM_SENSORS;

            response.buffer[0] = (state.sensors[i].temperature.value & 0xff00) >> 8;
            response.buffer[1] = (state.sensors[i].temperature.value & 0x00ff) >> 0;
            response.buffer[2] = (state.sensors[i].temperature.min & 0xff00) >> 8;
            response.buffer[3] = (state.sensors[i].temperature.min & 0x00ff) >> 0;
            response.buffer[4] = (state.sensors[i].temperature.max & 0xff00) >> 8;
            response.buffer[5] = (state.sensors[i].temperature.max & 0x00ff) >> 0;
            response.buffer[6] = state.sensors[i].temperature.valid;

            response.length = WATER_SENSOR_TEMPERATURE_RAW_SIZE;

            break;
        }
        case WATER_SENSOR_READ_CONFIG:
        {
            response.buffer[0] = (config.defaultLevel & 0xff00) >> 8;
            response.buffer[1] = (config.defaultLevel & 0x00ff) >> 0;

            response.length = WATER_SENSOR_CONFIG_SIZE;

            break;
        }
        case WATER_SENSOR_WRITE_CONFIG:
        {
            if (countToRead != 4) {
                response.nack = true;
                return;
            }

            if (!_read(WATER_SENSOR_CONFIG_SIZE)) {
                response.nack = true;
                return;
            }

            config.defaultLevel = (response.buffer[0] << 8) | response.buffer[1];

            break;
        }
        case WATER_SENSOR_READ_LEVEL_CONFIG:
        {
            if (countToRead != 2) {
                response.nack = true;
                return;
            }

            int channel = Wire.read();

            int i = channel / NUM_CHANNELS;
            int j = channel % NUM_CHANNELS;

            response.buffer[0] = config.sensors[i].adc[j].enabled ? 1 : 0;
            response.buffer[1] = (config.sensors[i].adc[j].samples & 0xff00) >> 8;
            response.buffer[2] = (config.sensors[i].adc[j].samples & 0x00ff) >> 0;
            response.buffer[3] = config.sensors[i].adc[j].alpha;
            response.buffer[4] = (config.sensors[i].adc[j].offset & 0xff00) >> 8;
            response.buffer[5] = (config.sensors[i].adc[j].offset & 0x00ff) >> 0;
            response.buffer[6] = (config.sensors[i].adc[j].level & 0xff00) >> 8;
            response.buffer[7] = (config.sensors[i].adc[j].level & 0x00ff) >> 0;

            response.length = WATER_SENSOR_LEVEL_CONFIG_SIZE;

            break;
        }
        case WATER_SENSOR_WRITE_LEVEL_CONFIG:
        {
            if (countToRead != 11) {
                response.nack = true;
                return;
            }

            int channel = Wire.read();

            int i = channel / NUM_CHANNELS;
            int j = channel % NUM_CHANNELS;

            if (!_read(WATER_SENSOR_LEVEL_CONFIG_SIZE)) {
                response.nack = true;
                return;
            }
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

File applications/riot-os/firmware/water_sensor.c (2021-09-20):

/*
 * Copyright (C) 2021 Bas Stottelaar <basstottelaar@gmail.com>
 *
 * This file is subject to the terms and conditions of the GNU Lesser
 * General Public License v2.1. See the file LICENSE in the top level
 * directory for more details.
 */

/**
 * @ingroup     drivers_water_sensor
 * @{
 *
 * @file
 * @brief       Implementation of the water level sensor.
 *
 * @author      Bas Stottelaar <basstottelaar@gmail.com>
 *
 * @}
 */

#include "water_sensor.h"
#include "water_sensor_internals.h"

#define ENABLE_DEBUG 0
#include "debug.h"

#define WATER_SENSOR_I2C     (dev->params.i2c_dev)
#define WATER_SENSOR_ADDR    (dev->params.address)

static uint8_t _checksum(const uint8_t *data, size_t length)
{
    uint8_t checksum = 0xff;

    for (unsigned i = 0; i < length; i++) {
        checksum ^= data[i];
    }

    return checksum;
}

static int _cmd(const water_sensor_t *dev, uint8_t cmd)
{
    int result;

    i2c_acquire(WATER_SENSOR_I2C);
    result = i2c_write_byte(WATER_SENSOR_I2C, WATER_SENSOR_ADDR, cmd, 0);
    i2c_release(WATER_SENSOR_I2C);

    return result;
}

static int _read_reg(const water_sensor_t *dev, uint8_t reg, void *data, size_t length)
{
    int result;

    i2c_acquire(WATER_SENSOR_I2C);
    result = i2c_read_regs(WATER_SENSOR_I2C, WATER_SENSOR_ADDR, reg, data, length, 0);
    i2c_release(WATER_SENSOR_I2C);

    return result;
}

static int _read_reg16(const water_sensor_t *dev, uint16_t reg, void *data, size_t length)
{
    int result;

    i2c_acquire(WATER_SENSOR_I2C);
    result = i2c_read_regs(WATER_SENSOR_I2C, WATER_SENSOR_ADDR, reg, data, length, I2C_REG16);
    i2c_release(WATER_SENSOR_I2C);

    return result;
}

static int _write_reg(const water_sensor_t *dev, uint8_t reg, const void *data, size_t length)
{
    int result;

    i2c_acquire(WATER_SENSOR_I2C);
    result = i2c_write_regs(WATER_SENSOR_I2C, WATER_SENSOR_ADDR, reg, data, length, 0);
    i2c_release(WATER_SENSOR_I2C);

    return result;
}

static int _write_reg16(const water_sensor_t *dev, uint16_t reg, const void *data, size_t length)
{
    int result;

    i2c_acquire(WATER_SENSOR_I2C);
    result = i2c_write_regs(WATER_SENSOR_I2C, WATER_SENSOR_ADDR, reg, data, length, I2C_REG16);
    i2c_release(WATER_SENSOR_I2C);

    return result;
}

int water_sensor_init(water_sensor_t *dev, const water_sensor_params_t *params)
{
    /* initialize the device descriptor */
    dev->params = *params;

    /* reset the device */
    if (water_sensor_reset(dev) != WATER_SENSOR_OK) {
        DEBUG("[water_sensor] water_sensor_init: reset failed\n");
        return WATER_SENSOR_ERR_I2C;
    }

    /* read sensor identification */
    water_sensor_info_t info;

    if (water_sensor_read_info(dev, &info) != WATER_SENSOR_OK) {
        DEBUG("[water_sensor] water_sensor_init: info failed\n");
        return WATER_SENSOR_ERR_I2C;
    }

    if (info.id != WATER_SENSOR_ID) {
        DEBUG("[water_sensor] water_sensor_init: identification failed\n");
        return WATER_SENSOR_ERR_NODEV;
    }

    if (info.errors != 0) {
        DEBUG("[water_sensor] water_sensor_init: sensor errors is %02x (context %d)\n", info.errors, info.context);
        return WATER_SENSOR_ERR_NODEV;
    }

    return WATER_SENSOR_OK;
}

int water_sensor_reset(const water_sensor_t *dev)
{
    if (_cmd(dev, WATER_SENSOR_RESET) != 0) {
        DEBUG("[water_sensor] water_sensor_reset: failed\n");
        return WATER_SENSOR_ERR_I2C;
    }

    return WATER_SENSOR_OK;
}

int water_sensor_enable(const water_sensor_t *dev)
{
    if (_cmd(dev, WATER_SENSOR_ENABLE) != 0) {
        DEBUG("[water_sensor] water_sensor_enable: failed\n");
        return WATER_SENSOR_ERR_I2C;
    }

    return WATER_SENSOR_OK;
}

int water_sensor_load(const water_sensor_t *dev)
{
    if (_cmd(dev, WATER_SENSOR_LOAD) != 0) {
        DEBUG("[water_sensor] water_sensor_load: failed\n");
        return WATER_SENSOR_ERR_I2C;
    }

    return WATER_SENSOR_OK;
}

int water_sensor_store(const water_sensor_t *dev)
{
    if (_cmd(dev, WATER_SENSOR_STORE) != 0) {
        DEBUG("[water_sensor] water_sensor_store: failed\n");
        return WATER_SENSOR_ERR_I2C;
    }

    return WATER_SENSOR_OK;
}

int water_sensor_calibrate(const water_sensor_t *dev)
{
    if (_cmd(dev, WATER_SENSOR_CALIBRATE) != 0) {
        DEBUG("[water_sensor] water_sensor_calibrate: failed\n");
        return WATER_SENSOR_ERR_I2C;
    }

    return WATER_SENSOR_OK;
}

int water_sensor_zero(const water_sensor_t *dev)
{
    if (_cmd(dev, WATER_SENSOR_ZERO) != 0) {
        DEBUG("[water_sensor] water_sensor_zero: failed\n");
        return WATER_SENSOR_ERR_I2C;
    }

    return WATER_SENSOR_OK;
}

int water_sensor_read_info(const water_sensor_t *dev, water_sensor_info_t *out)
{
    assert(out != NULL);

    uint8_t buf[WATER_SENSOR_INFO_SIZE + 1];

    if (_read_reg(dev, WATER_SENSOR_READ_INFO, buf, sizeof(buf)) != 0) {
        DEBUG("[water_sensor] water_sensor_read_info: failed\n");
        return WATER_SENSOR_ERR_I2C;
    }

    if (_checksum(buf, WATER_SENSOR_INFO_SIZE) != buf[6]) {
        DEBUG("[water_sensor] water_sensor_read_info: checksum error\n");
        return WATER_SENSOR_ERR_I2C;
    }

    out->id = buf[0];
    out->level_channels = buf[1];
    out->temperature_channels = buf[2];
    out->enabled = buf[3];
    out->errors = buf[4];
    out->context = buf[5];

    return WATER_SENSOR_OK;
}

int water_sensor_read_level(const water_sensor_t *dev, water_sensor_level_t *out)
{
    assert(out != NULL);

    uint8_t buf[WATER_SENSOR_LEVEL_SIZE + 1];

    if (_read_reg(dev, WATER_SENSOR_READ_LEVEL, buf, sizeof(buf)) != 0) {
        DEBUG("[water_sensor] water_sensor_read_level: failed\n");
        return WATER_SENSOR_ERR_I2C;
    }

    if (_checksum(buf, WATER_SENSOR_TEMPERATURE_SIZE) != buf[4]) {
        DEBUG("[water_sensor] water_sensor_read_level: checksum error\n");
        return WATER_SENSOR_ERR_I2C;
    }

    out->value = (buf[0] << 8) | buf[1];
    out->channel = buf[2];
    out->valid = buf[3] != 0;

    return WATER_SENSOR_OK;
}
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
